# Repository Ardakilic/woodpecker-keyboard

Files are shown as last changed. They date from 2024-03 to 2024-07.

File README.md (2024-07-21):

# Woodpecker Keyboard
5 row ortholinear keyboard, based on [Lumberelite](https://github.com/tjeffree/lumberelite) and [Lumberjack](https://github.com/peej/lumberjack-keyboard).

The fork is done in a way that a wireless controller such as [nice!nano](https://nicekeyboards.com/nice-nano/) or [alternatives](https://github.com/joric/nrfmicro/wiki/Alternatives) could be utilized, and OLED module, Pimoroni Trackball or Cirque Trackpad could be applied over to the central area of the keyboard.

Preview0 preview 0

Preview1 preview 1

All work on the PCB is done by [Özkan Çelik](https://github.com/ozkan), he made this due to my request.

Shields are done by Kazim Kaba and [Ender Piyale](https://github.com/enderpiyale/).

[The plates of Lumberjack Keyboard](https://github.com/peej/lumberjack-keyboard/tree/master/plates) work nicely. I'm currently using the `lumberjack-split` flavour on my board, which you can also find [here](./plates-shields/plates/lumberjack-split.dxf).

Additionally, the board is compatible with 60% cases. My case is a wooden one from a Chinese e-commerce website. I raised the micro controller with sockets to not to drill a hole into my case.

## Firmware

* QMK: Keyboard definition and userspace
    * https://github.com/Ardakilic/qmk_firmware/tree/master/keyboards/woodpecker
    * https://github.com/Ardakilic/qmk_userspace/tree/main/keyboards/woodpecker
* ZMK: https://github.com/ardakilic/zmk-config-woodpecker

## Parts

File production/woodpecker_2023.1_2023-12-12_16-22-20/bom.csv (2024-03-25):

Designator | Footprint | Quantity | Value | LCSC Part #
BT1 | PinHeader_1x02_P2.54mm_Vertical | 1 | Battery_Cell
D_1_1, D_1_10, D_1_11, D_1_12, D_1_2, D_1_3, D_1_4, D_1_5, D_1_6, D_1_7, D_1_8, D_1_9, D_2_1, D_2_10, D_2_11, D_2_12, D_2_2, D_2_3, D_2_4, D_2_5, D_2_6, D_2_7, D_2_8, D_2_9, D_3_1, D_3_10, D_3_11, D_3_12, D_3_2, D_3_3, D_3_4, D_3_5, D_3_6, D_3_7, D_3_8, D_3_9, D_4_1, D_4_10, D_4_11, D_4_12, D_4_2, D_4_3, D_4_4, D_4_5, D_4_6, D_4_7, D_4_8, D_4_9, D_5_1, D_5_10, D_5_11, D_5_12, D_5_2, D_5_3, D_5_4, D_5_5, D_5_6, D_5_7, D_5_8, D_5_9 | Diode-dual | 60 | 1N4148
H1, H2, H3, H4 | MountingHole_2.2mm_M2_DIN965_Pad | 4 | M2 16mm Spacer
H10, H11, H8, H9 | M2_Threads_v2 | 4 | MountingHole
H5 | Bumpon_3M_F0502 | 1 | ~
H6, H7 | MountingHole_2.2mm_M2_elongated | 2 | ~
HOLE_2, HOLE | Graphic_Mask_HalfHole | 2 | Graphic_Mask_HalfHole
J1 | PinHeader_1x03_P2.54mm_Vertical | 1 | Conn_01x03_Pin
OLED1 | OLED_v2 | 1 | SSD1306
RESET1, RESET2 | SW_SPST_RS-282G05A3-SM | 2 | SW_PUSH
SW1 | MSK12C02 | 1 | MSK12C02
SW2 | SS12D00 | 1 | SS12D00
SW_1_1, SW_1_10, SW_1_11, SW_1_12, SW_1_2, SW_1_3, SW_1_4, SW_1_5, SW_1_6, SW_1_7, SW_1_8, SW_1_9, SW_2_1, SW_2_10, SW_2_11, SW_2_12, SW_2_2, SW_2_3, SW_2_4, SW_2_5, SW_2_6, SW_2_7, SW_2_8, SW_2_9, SW_3_1, SW_3_10, SW_3_11, SW_3_12, SW_3_2, SW_3_3, SW_3_4, SW_3_5, SW_3_6, SW_3_7, SW_3_8, SW_3_9, SW_4_1, SW_4_10, SW_4_11, SW_4_12, SW_4_2, SW_4_3, SW_4_4, SW_4_5, SW_4_6, SW_4_7, SW_4_8, SW_4_9, SW_5_1, SW_5_10, SW_5_11, SW_5_12, SW_5_2, SW_5_3, SW_5_4, SW_5_5, SW_5_6, SW_5_7, SW_5_8, SW_5_9 | SW_MX_PG1350_NoLed | 60 | MX-compatible or Kailh Choc v1
TB1 | PIM447 | 1 | PIM447

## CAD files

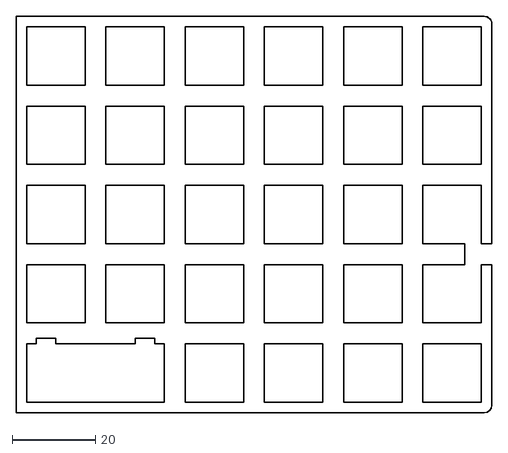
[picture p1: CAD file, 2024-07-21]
plates-shields/plates/lumberjack-split.dxf
114.3 x 95.2

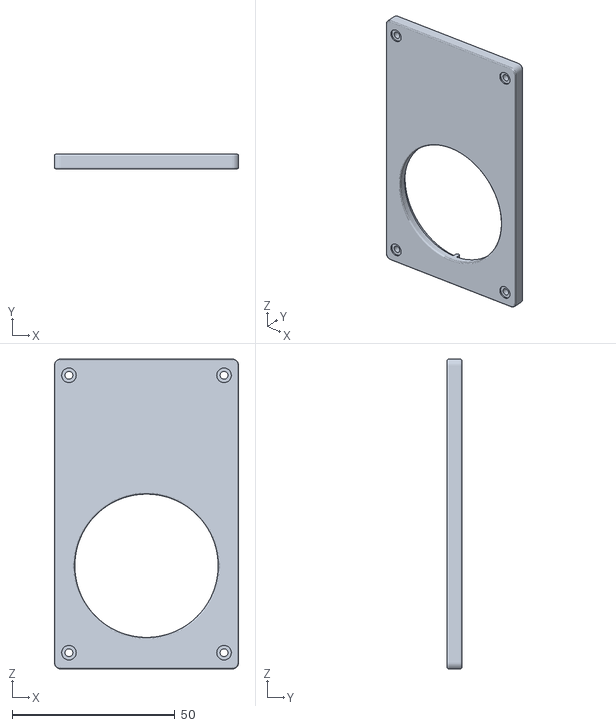
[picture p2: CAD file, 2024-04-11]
plates-shields/shields/trackpad only.stl
56.6 x 4.50 x 95.2

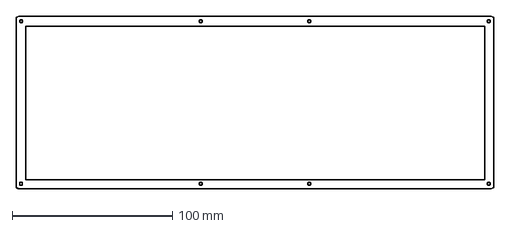
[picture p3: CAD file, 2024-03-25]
plates-shields/plates/woodpecker-split v18 - Mid.dxf
297.8 x 107.4 mm

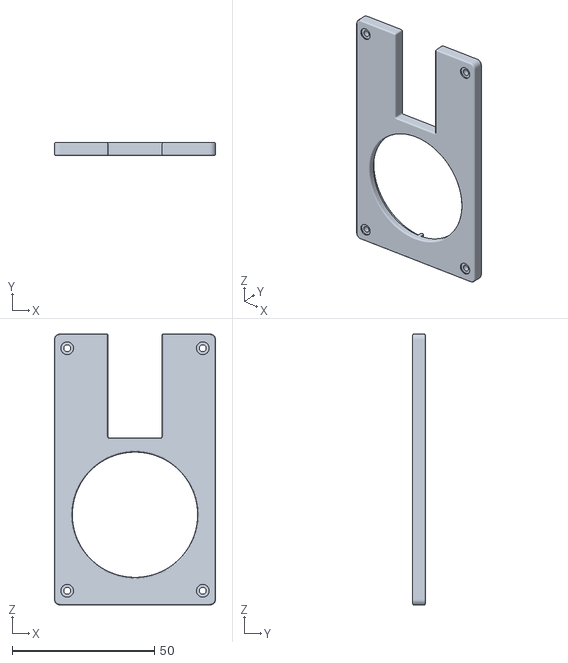
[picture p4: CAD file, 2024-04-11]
plates-shields/shields/with oled.stl
56.6 x 4.50 x 95.2

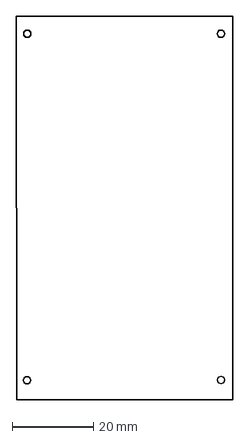
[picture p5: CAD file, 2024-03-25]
plates-shields/plates/woodpecker-split v18 - Center.dxf
53.1 x 94.3 mm

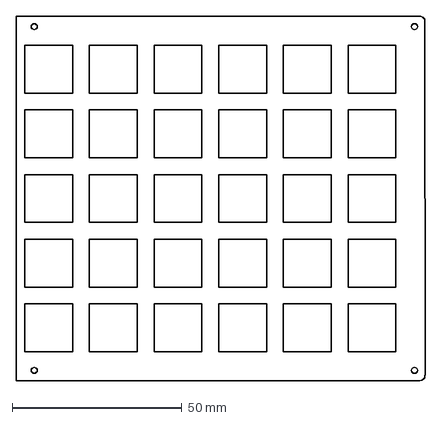
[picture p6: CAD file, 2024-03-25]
plates-shields/plates/woodpecker-split v18 - Top.dxf
120.5 x 107.4 mm

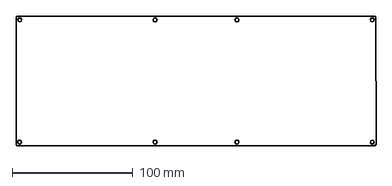
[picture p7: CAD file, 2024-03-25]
plates-shields/plates/woodpecker-split v18 - Bottom.dxf
297.8 x 107.4 mm

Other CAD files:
plates-shields/shields/woodpecker.f3d

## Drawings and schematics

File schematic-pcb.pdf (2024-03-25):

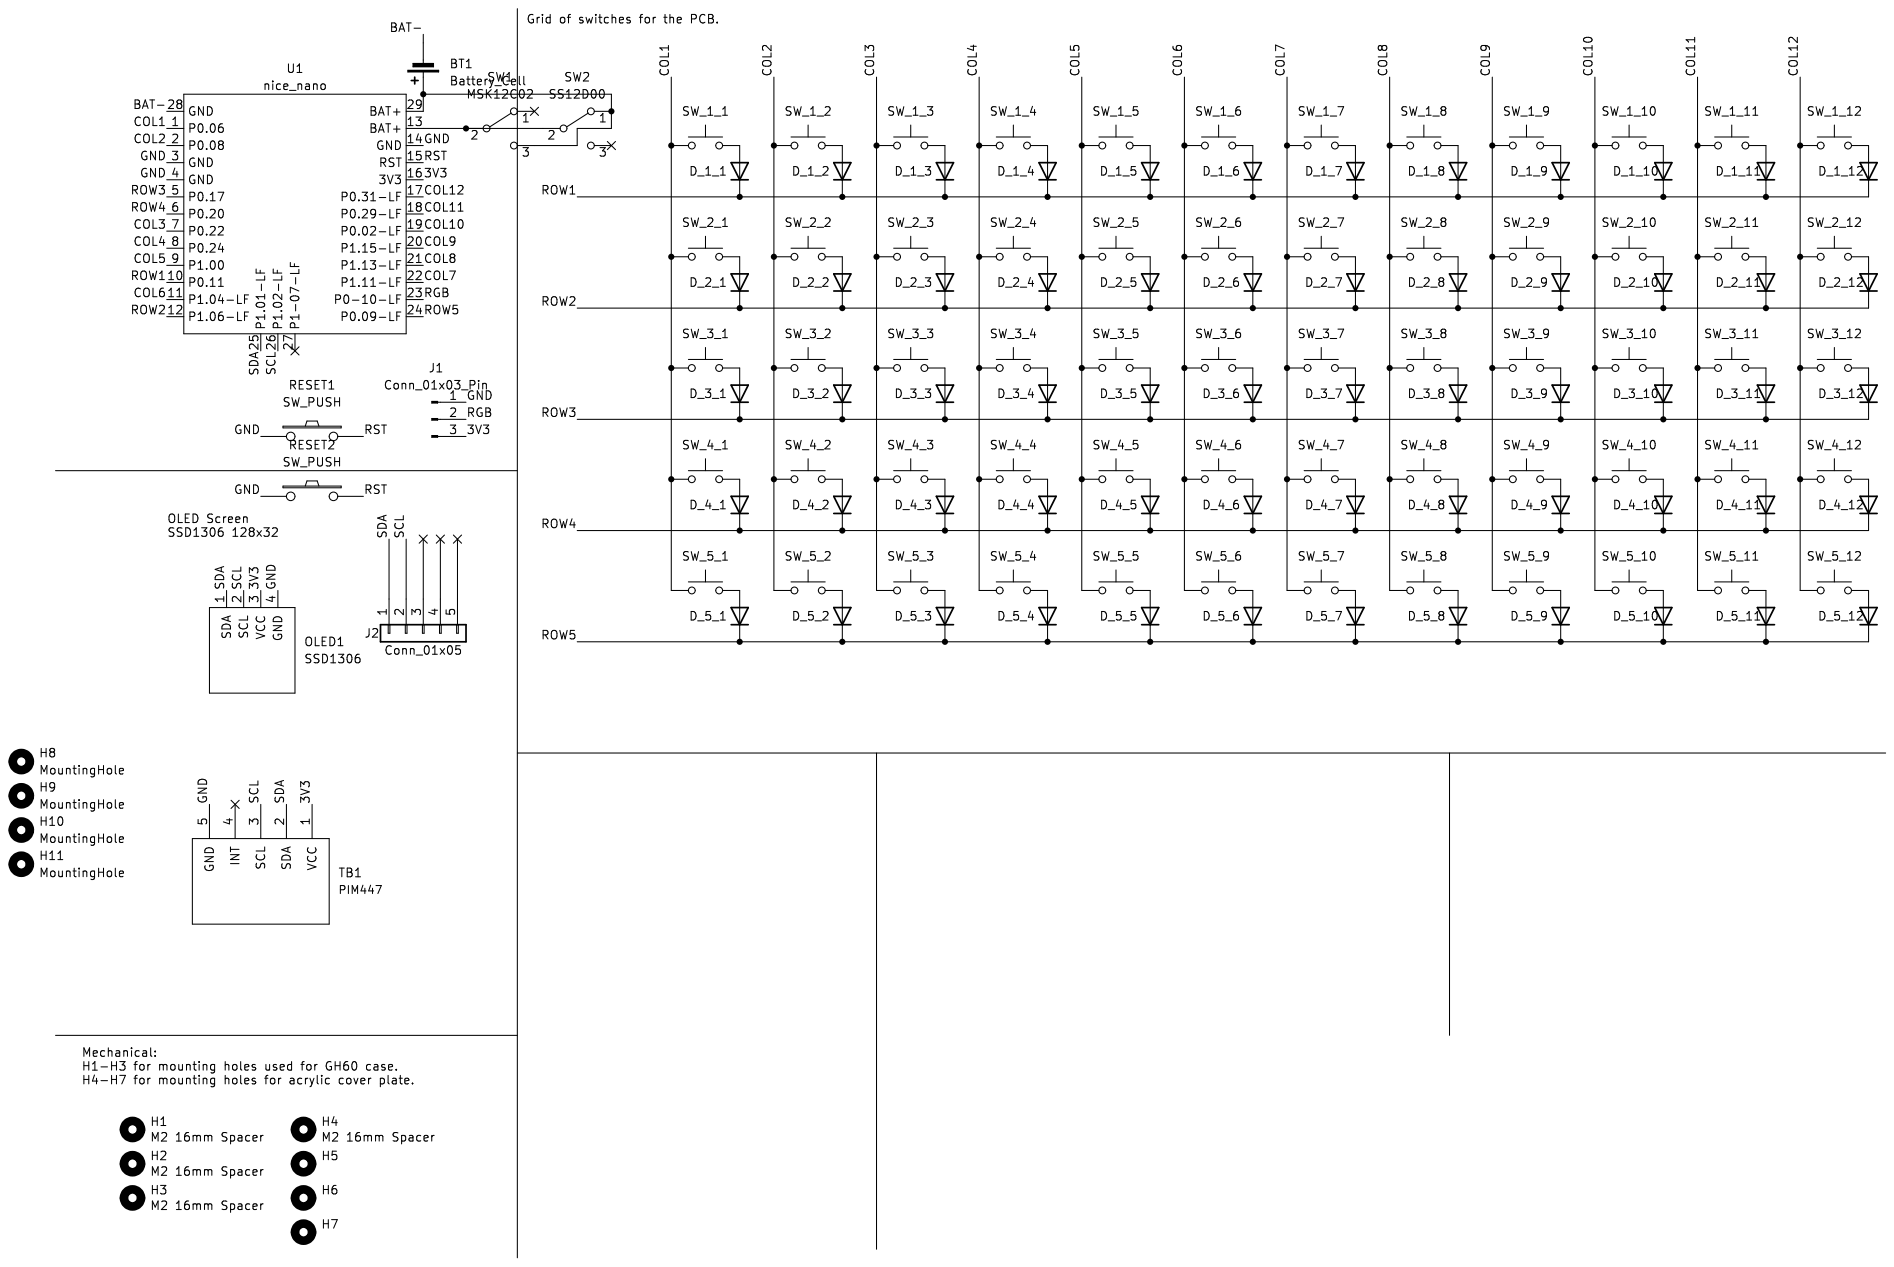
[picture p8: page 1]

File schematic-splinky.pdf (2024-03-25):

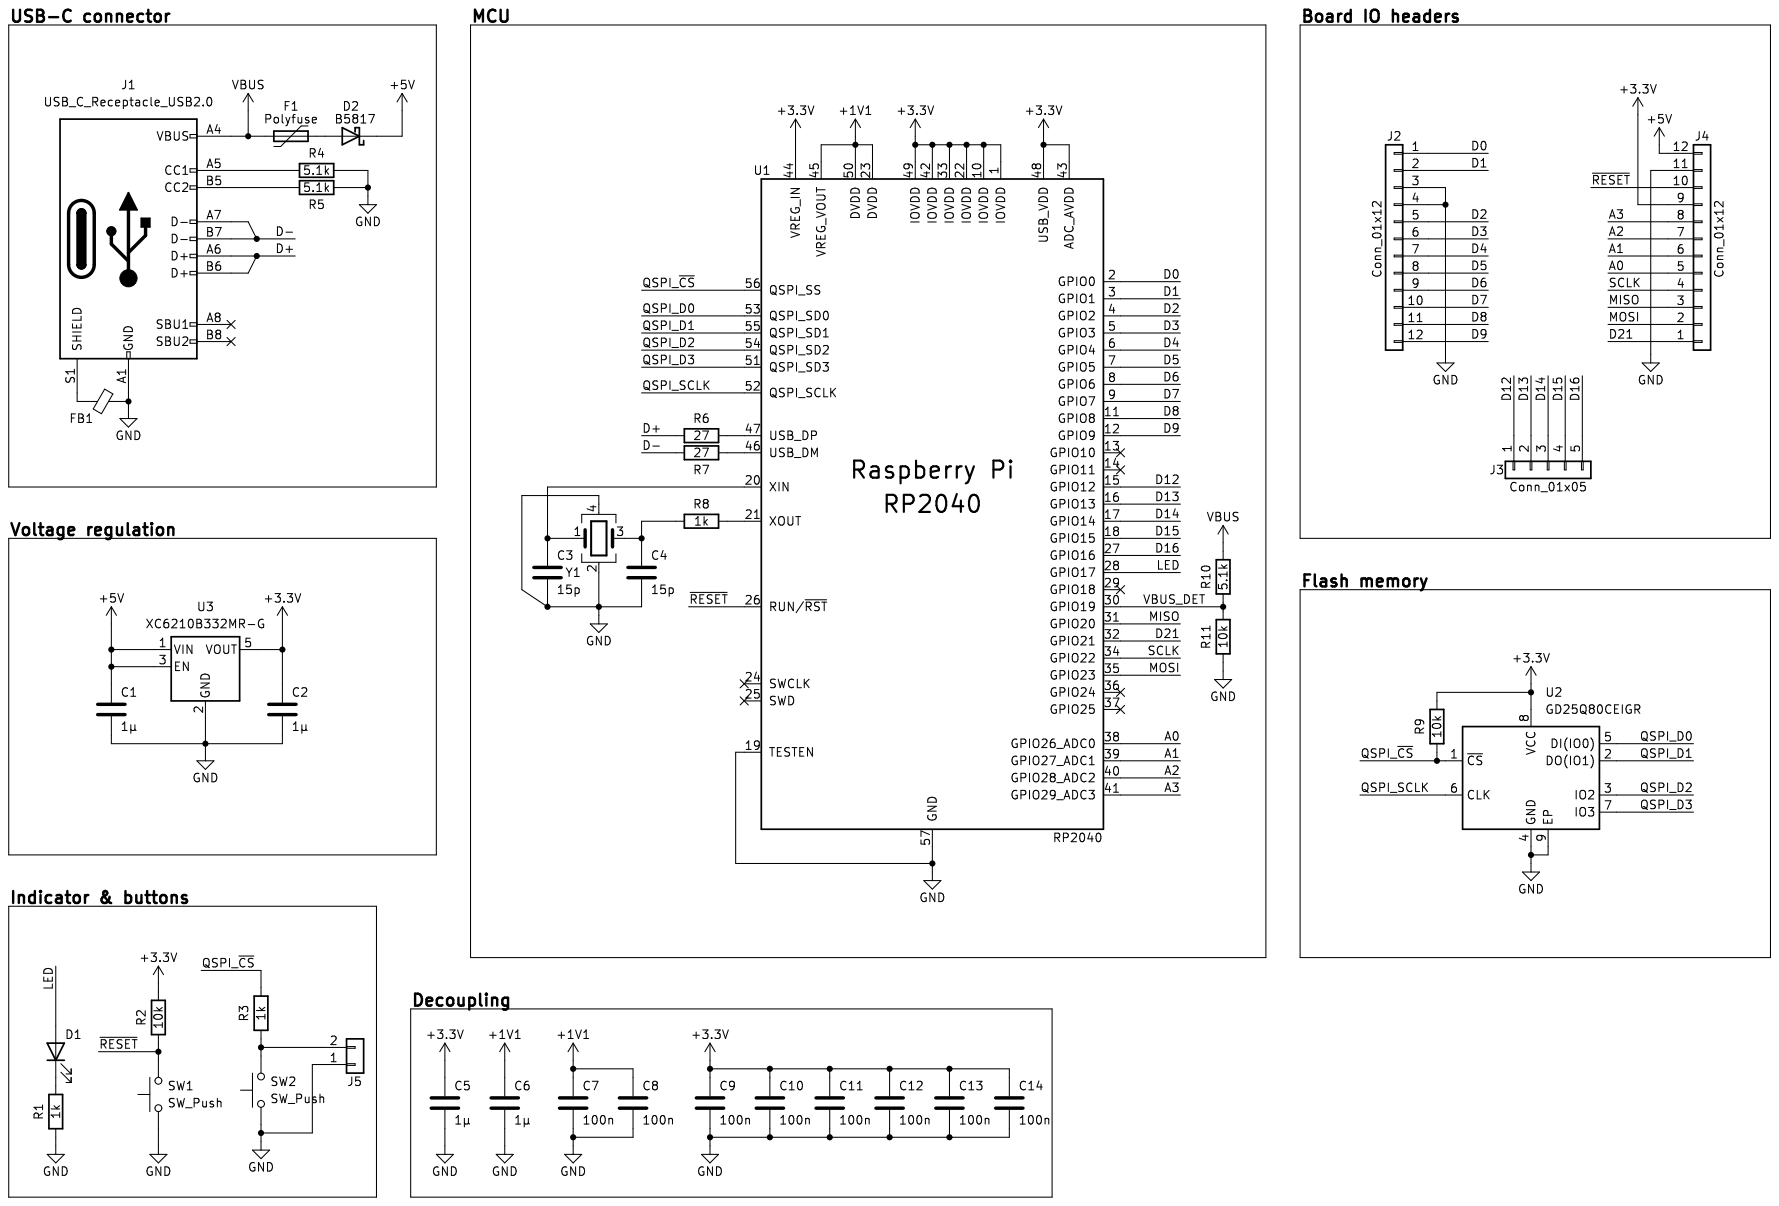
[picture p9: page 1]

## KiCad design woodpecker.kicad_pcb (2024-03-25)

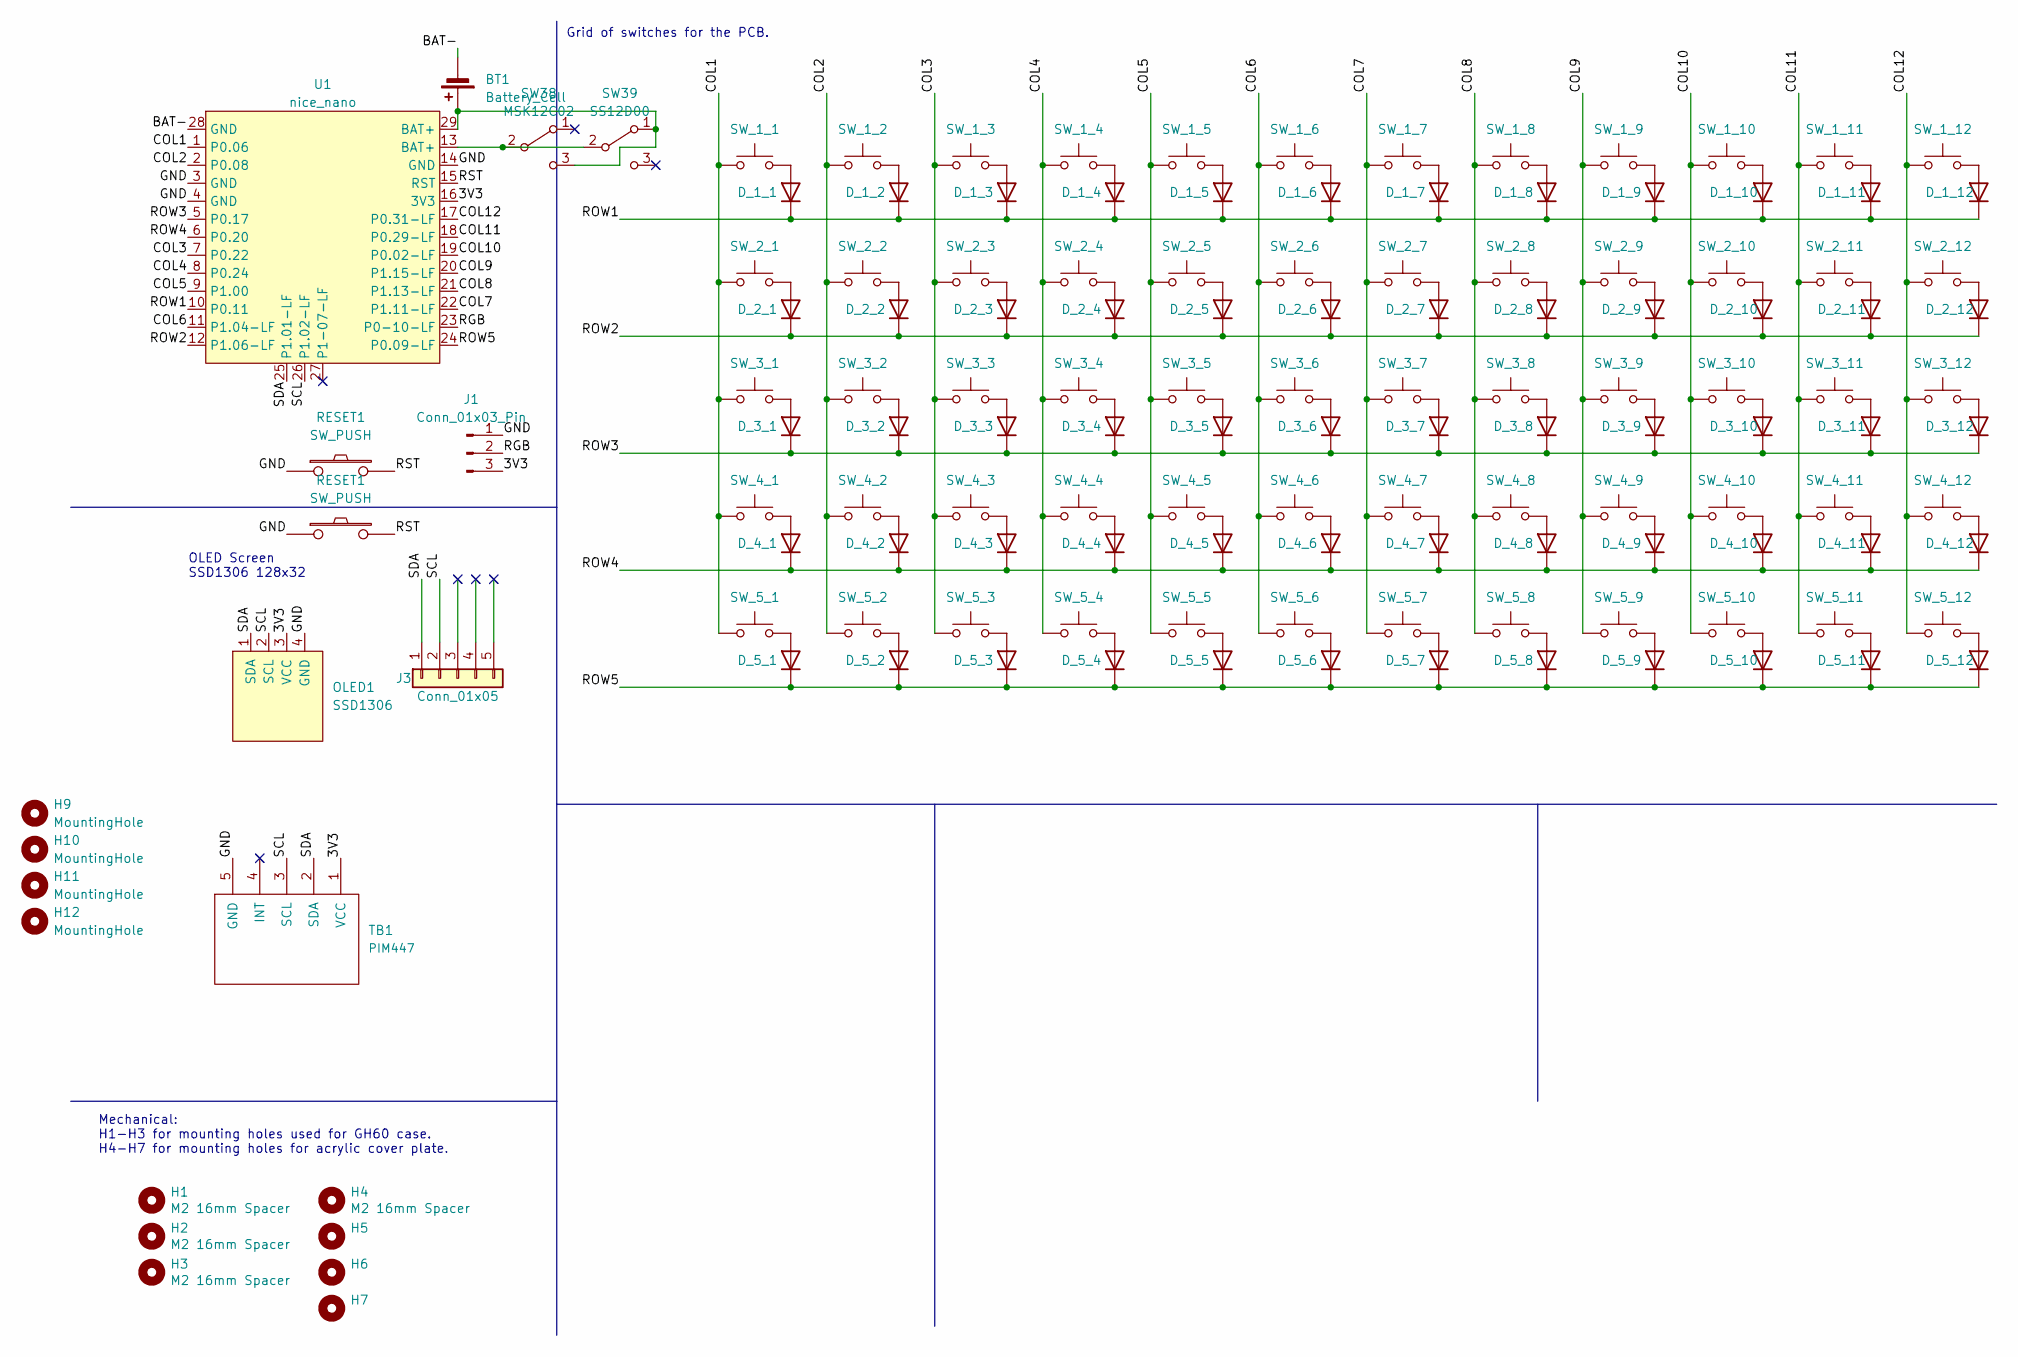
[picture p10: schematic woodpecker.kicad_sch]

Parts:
BT1: Battery_Cell; PinHeader_1x02_P2.54mm_Vertical
D_1_1, D_1_2, D_1_3, D_1_4, D_1_5, D_1_6, D_1_7, D_1_8, D_1_9, D_1_10, D_1_11, D_1_12, D_2_1, D_2_2, D_2_3, D_2_4, D_2_5, D_2_6, D_2_7, D_2_8, D_2_9, D_2_10, D_2_11, D_2_12, D_3_1, D_3_2, D_3_3, D_3_4, D_3_5, D_3_6, D_3_7, D_3_8, D_3_9, D_3_10, D_3_11, D_3_12, D_4_1, D_4_2, D_4_3, D_4_4, D_4_5, D_4_6, D_4_7, D_4_8, D_4_9, D_4_10, D_4_11, D_4_12, D_5_1, D_5_2, D_5_3, D_5_4, D_5_5, D_5_6, D_5_7, D_5_8, D_5_9, D_5_10, D_5_11, D_5_12: 1N4148; Diode-dual
H1, H2, H3, H4: M2 16mm Spacer; MountingHole_2.2mm_M2_DIN965_Pad
H5: Bumpon_3M_F0502
H6, H7: MountingHole_2.2mm_M2_elongated
H9, H10, H11, H12: MountingHole; M2_Threads_v2
J1: Conn_01x03_Pin; PinHeader_1x03_P2.54mm_Vertical
J3: Conn_01x05; PinHeader_1x05_P2.54mm_Vertical
OLED1: SSD1306; OLED_v2
RESET1: SW_PUSH; SW_SPST_RS-282G05A3-SM
SW38: MSK12C02
SW39: SS12D00
SW_1_1, SW_1_2, SW_1_3, SW_1_4, SW_1_5, SW_1_6, SW_1_7, SW_1_8, SW_1_9, SW_1_10, SW_1_11, SW_1_12, SW_2_1, SW_2_2, SW_2_3, SW_2_4, SW_2_5, SW_2_6, SW_2_7, SW_2_8, SW_2_9, SW_2_10, SW_2_11, SW_2_12, SW_3_1, SW_3_2, SW_3_3, SW_3_4, SW_3_5, SW_3_6, SW_3_7, SW_3_8, SW_3_9, SW_3_10, SW_3_11, SW_3_12, SW_4_1, SW_4_2, SW_4_3, SW_4_4, SW_4_5, SW_4_6, SW_4_7, SW_4_8, SW_4_9, SW_4_10, SW_4_11, SW_4_12, SW_5_1, SW_5_2, SW_5_3, SW_5_4, SW_5_5, SW_5_6, SW_5_7, SW_5_8, SW_5_9, SW_5_10, SW_5_11, SW_5_12: MX-compatible or Kailh Choc v1; SW_MX_PG1350_NoLed
TB1: PIM447
U1: nice_nano; nice_nano_AH_Reversible

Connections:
/3V3: J1.3, OLED1.3 (VCC), TB1.1 (VCC), U1.16 (3V3)
/BAT-: BT1.2 (-), U1.28 (GND)
/COL1: SW_1_1.1, SW_2_1.1, SW_3_1.1, SW_4_1.1, SW_5_1.1, U1.1 (P0.06)
/COL2: SW_1_2.1, SW_2_2.1, SW_3_2.1, SW_4_2.1, SW_5_2.1, U1.2 (P0.08)
/COL3: SW_1_3.1, SW_2_3.1, SW_3_3.1, SW_4_3.1, SW_5_3.1, U1.7 (P0.22)
/COL4: SW_1_4.1, SW_2_4.1, SW_3_4.1, SW_4_4.1, SW_5_4.1, U1.8 (P0.24)
/COL5: SW_1_5.1, SW_2_5.1, SW_3_5.1, SW_4_5.1, SW_5_5.1, U1.9 (P1.00)
/COL6: SW_1_6.1, SW_2_6.1, SW_3_6.1, SW_4_6.1, SW_5_6.1, U1.11 (P1.04-LF)
/COL7: SW_1_7.1, SW_2_7.1, SW_3_7.1, SW_4_7.1, SW_5_7.1, U1.22 (P1.11-LF)
/COL8: SW_1_8.1, SW_2_8.1, SW_3_8.1, SW_4_8.1, SW_5_8.1, U1.21 (P1.13-LF)
/COL9: SW_1_9.1, SW_2_9.1, SW_3_9.1, SW_4_9.1, SW_5_9.1, U1.20 (P1.15-LF)
/COL10: SW_1_10.1, SW_2_10.1, SW_3_10.1, SW_4_10.1, SW_5_10.1, U1.19 (P0.02-LF)
/COL11: SW_1_11.1, SW_2_11.1, SW_3_11.1, SW_4_11.1, SW_5_11.1, U1.18 (P0.29-LF)
/COL12: SW_1_12.1, SW_2_12.1, SW_3_12.1, SW_4_12.1, SW_5_12.1, U1.17 (P0.31-LF)
/GND: J1.1, OLED1.4 (GND), RESET1.1, TB1.5 (GND), U1.3 (GND), U1.4 (GND), U1.14 (GND); also elsewhere on the board
/RGB: J1.2, U1.23 (P0-10-LF)
/ROW1: D_1_1.1 (K), D_1_2.1 (K), D_1_3.1 (K), D_1_4.1 (K), D_1_5.1 (K), D_1_6.1 (K), D_1_7.1 (K), D_1_8.1 (K), D_1_9.1 (K), D_1_10.1 (K), D_1_11.1 (K), D_1_12.1 (K), U1.10 (P0.11)
/ROW2: D_2_1.1 (K), D_2_2.1 (K), D_2_3.1 (K), D_2_4.1 (K), D_2_5.1 (K), D_2_6.1 (K), D_2_7.1 (K), D_2_8.1 (K), D_2_9.1 (K), D_2_10.1 (K), D_2_11.1 (K), D_2_12.1 (K), U1.12 (P1.06-LF)
/ROW3: D_3_1.1 (K), D_3_2.1 (K), D_3_3.1 (K), D_3_4.1 (K), D_3_5.1 (K), D_3_6.1 (K), D_3_7.1 (K), D_3_8.1 (K), D_3_9.1 (K), D_3_10.1 (K), D_3_11.1 (K), D_3_12.1 (K), U1.5 (P0.17)
/ROW4: D_4_1.1 (K), D_4_2.1 (K), D_4_3.1 (K), D_4_4.1 (K), D_4_5.1 (K), D_4_6.1 (K), D_4_7.1 (K), D_4_8.1 (K), D_4_9.1 (K), D_4_10.1 (K), D_4_11.1 (K), D_4_12.1 (K), U1.6 (P0.20)
/ROW5: D_5_1.1 (K), D_5_2.1 (K), D_5_3.1 (K), D_5_4.1 (K), D_5_5.1 (K), D_5_6.1 (K), D_5_7.1 (K), D_5_8.1 (K), D_5_9.1 (K), D_5_10.1 (K), D_5_11.1 (K), D_5_12.1 (K), U1.24 (P0.09-LF)
/RST: RESET1.2, U1.15 (RST); also elsewhere on the board
/SCL: OLED1.2 (SCL), TB1.3 (SCL), U1.26 (P1.02-LF); also elsewhere on the board
/SDA: OLED1.1 (SDA), TB1.2 (SDA), U1.25 (P1.01-LF); also elsewhere on the board
unnamed 24: BT1.1 (+), U1.29 (BAT+); also elsewhere on the board
unnamed: D_1_1.2 (A), SW_1_1.2
unnamed: D_1_2.2 (A), SW_1_2.2
unnamed: D_1_3.2 (A), SW_1_3.2
unnamed: D_1_4.2 (A), SW_1_4.2
unnamed: D_1_5.2 (A), SW_1_5.2
unnamed: D_1_6.2 (A), SW_1_6.2
unnamed: D_1_7.2 (A), SW_1_7.2
unnamed: D_1_8.2 (A), SW_1_8.2
unnamed: D_1_9.2 (A), SW_1_9.2
unnamed: D_1_10.2 (A), SW_1_10.2
unnamed: D_1_11.2 (A), SW_1_11.2
unnamed: D_1_12.2 (A), SW_1_12.2
unnamed: D_2_1.2 (A), SW_2_1.2
unnamed: D_2_2.2 (A), SW_2_2.2
unnamed: D_2_3.2 (A), SW_2_3.2
unnamed: D_2_4.2 (A), SW_2_4.2
unnamed: D_2_5.2 (A), SW_2_5.2
unnamed: D_2_6.2 (A), SW_2_6.2
unnamed: D_2_7.2 (A), SW_2_7.2
unnamed: D_2_8.2 (A), SW_2_8.2
unnamed: D_2_9.2 (A), SW_2_9.2
unnamed: D_2_10.2 (A), SW_2_10.2
unnamed: D_2_11.2 (A), SW_2_11.2
unnamed: D_2_12.2 (A), SW_2_12.2
unnamed: D_3_1.2 (A), SW_3_1.2
unnamed: D_3_2.2 (A), SW_3_2.2
unnamed: D_3_3.2 (A), SW_3_3.2
unnamed: D_3_4.2 (A), SW_3_4.2
unnamed: D_3_5.2 (A), SW_3_5.2
unnamed: D_3_6.2 (A), SW_3_6.2
unnamed: D_3_7.2 (A), SW_3_7.2
unnamed: D_3_8.2 (A), SW_3_8.2
unnamed: D_3_9.2 (A), SW_3_9.2
unnamed: D_3_10.2 (A), SW_3_10.2
unnamed: D_3_11.2 (A), SW_3_11.2
unnamed: D_3_12.2 (A), SW_3_12.2
unnamed: D_4_1.2 (A), SW_4_1.2
unnamed: D_4_2.2 (A), SW_4_2.2
unnamed: D_4_3.2 (A), SW_4_3.2
unnamed: D_4_4.2 (A), SW_4_4.2
unnamed: D_4_5.2 (A), SW_4_5.2
unnamed: D_4_6.2 (A), SW_4_6.2
unnamed: D_4_7.2 (A), SW_4_7.2
unnamed: D_4_8.2 (A), SW_4_8.2
unnamed: D_4_9.2 (A), SW_4_9.2
unnamed: D_4_10.2 (A), SW_4_10.2
unnamed: D_4_11.2 (A), SW_4_11.2
unnamed: D_4_12.2 (A), SW_4_12.2
unnamed: D_5_1.2 (A), SW_5_1.2
unnamed: D_5_2.2 (A), SW_5_2.2
unnamed: D_5_3.2 (A), SW_5_3.2
unnamed: D_5_4.2 (A), SW_5_4.2
unnamed: D_5_5.2 (A), SW_5_5.2
unnamed: D_5_6.2 (A), SW_5_6.2
unnamed: D_5_7.2 (A), SW_5_7.2
unnamed: D_5_8.2 (A), SW_5_8.2
unnamed: D_5_9.2 (A), SW_5_9.2
unnamed: D_5_10.2 (A), SW_5_10.2
unnamed: D_5_11.2 (A), SW_5_11.2
unnamed: D_5_12.2 (A), SW_5_12.2
unnamed 85: U1.13 (BAT+); also elsewhere on the board

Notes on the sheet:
Grid of switches for the PCB.
OLED Screen SSD1306 128x32
Mechanical: H1-H3 for mounting holes used for GH60 case. H4-H7 for mounting holes for acrylic cover plate.

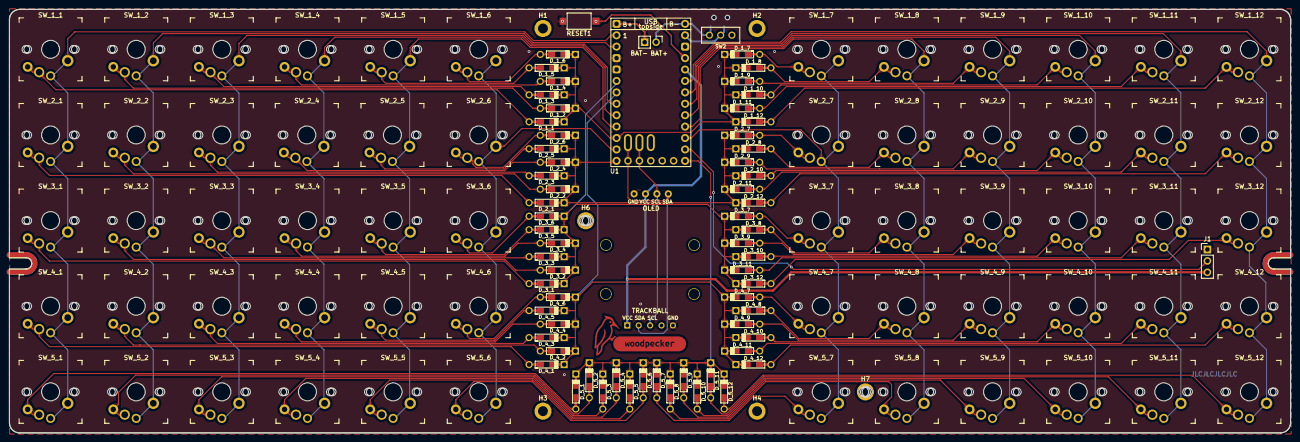
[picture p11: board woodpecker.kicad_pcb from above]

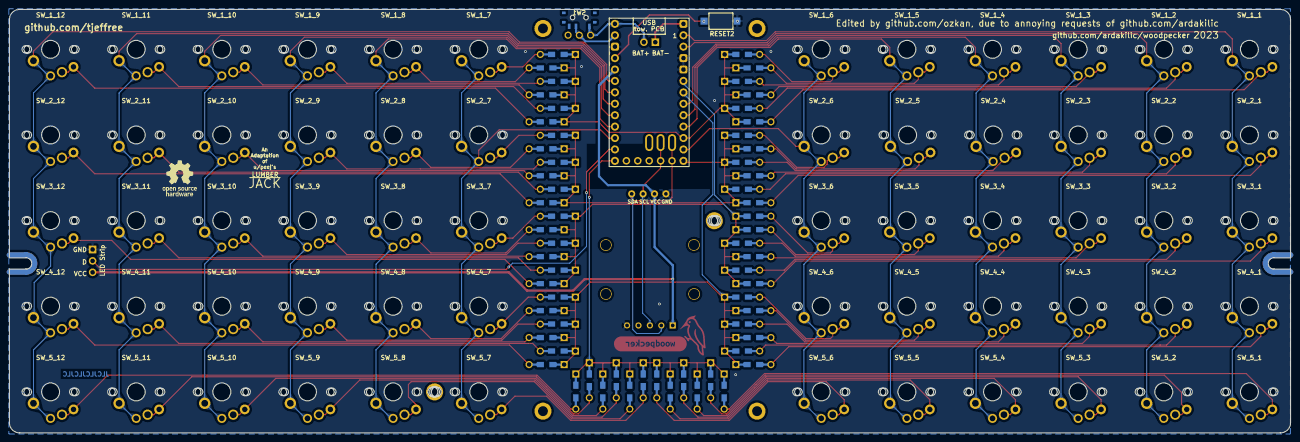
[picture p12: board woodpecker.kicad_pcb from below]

Board: 2 copper layers, 285.0 x 94.2 mm, 144 parts (2 on the bottom side), 86 nets.

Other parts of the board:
H8: MountingHole; M2_Threads_v2
HOLE: Graphic_Mask_HalfHole
HOLE#2: Graphic_Mask_HalfHole
J2: Conn_01x05; PinHeader_1x05_P2.54mm_Vertical
RESET2: SW_PUSH; SW_SPST_RS-282G05A3-SM
SW1: MSK12C02
SW2: SS12D00
kibuzzard-656122B9: G***; kibuzzard-656122B9

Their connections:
/GND: RESET2.1; also elsewhere on the board
/RST: RESET2.2; also elsewhere on the board
/SCL: J2.2; also elsewhere on the board
/SDA: J2.1; also elsewhere on the board
unnamed 24: SW1.3 (C), SW2.1 (A); also elsewhere on the board
unnamed 85: SW1.2 (B), SW2.2 (B); also elsewhere on the board

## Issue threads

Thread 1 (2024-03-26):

What's the use case?

FoxxMD, 2024-03-26:
The entire setup is beautiful! Love those keycap colros and font, and the case is gorgeous.

I understand the split can be more ergonomic as wrists are further apart. What does the ortholinear layout contribute? And how are you using the middle space?

Ardakilic, 2024-03-26:
The middle space is there not to bent your wrists a lot. It's like unibody split keyboard, and feels better. I can say this as a old planck keyboard user.

Ortholinear layout contributes a lot, you can watch Planck keyboard's introduction video here, it adverties ortholinear more than the product itself 😊  https://www.youtube.com/watch?v=bEPg8kk84gw

In the futue, I'm planning to utilize a trackpad there, but the driver for ZMK firmware did not merge it yet, so I'm waiting patiently.

Closed 2024-03-28.

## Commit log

2024-03-25 Upload the board to GitHub
    [woodpecker-split v18 - Bottom.dxf, woodpecker-split v18 - Center.dxf, woodpecker-split v18 - Mid.dxf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]
2024-03-25 include bom and pos files, modify gitignore
    [bom.csv, designators.csv, positions.csv]
2024-04-11 Shields added, thanks to @enderpiyale
    [trackpad only.stl, with oled.stl, woodpecker-split v18 - Bottom.dxf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]
2024-07-21 chore: copy add lumberjack split plate into the repository, clean up README
    [lumberjack-split.dxf]
2024-10-27 feature: shield f3d project added
    [woodpecker.f3d]
